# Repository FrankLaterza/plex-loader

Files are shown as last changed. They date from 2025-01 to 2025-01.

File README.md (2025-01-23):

# Plex Loader
A PCB designed to route traffic for flashing many devices with one central programmer.

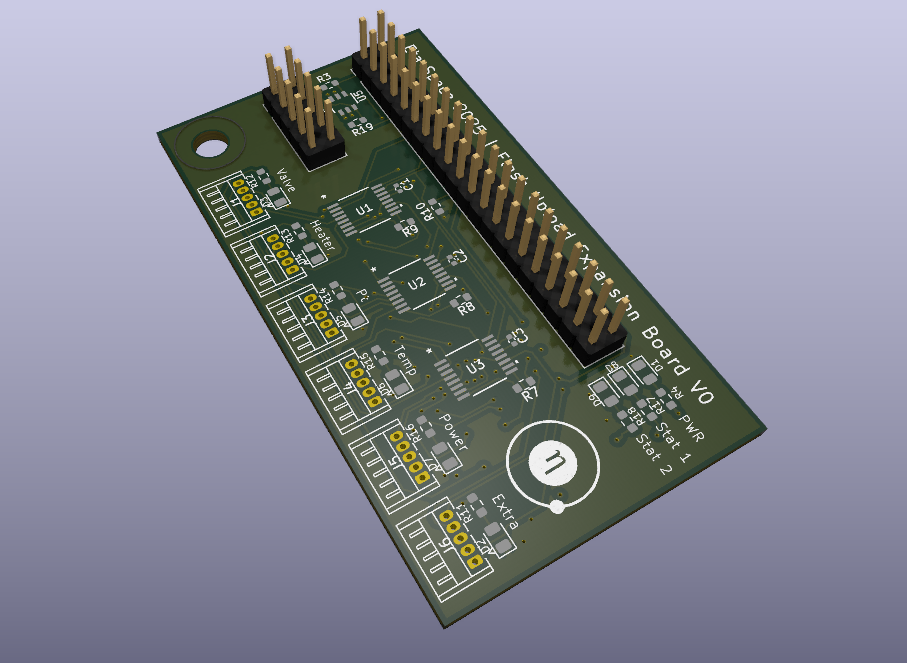
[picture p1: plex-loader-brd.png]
alttxt


BOM (per unit) 💣
| Parts | QT | Description | Link |
|---|---|---|---|
| TMUX1208 | 3 | Bidirectional Multiplexer | [link](https://digikey.com/en/products/detail/texas-instruments/TMUX1208PWR/9746210) |
dsPIC33f | 1 | An extra PIC for testing | [link](https://www.digikey.com/en/products/detail/microchip-technology/DSPIC33FJ128GP204-E-PT/1635665) |
| MOSFET PNP | 1 | Used as pain power switch | [link](https://www.digikey.com/en/products/detail/vishay-siliconix/sq3457ev-t1-ge3/7566744) |
| 0.1uf Cap | 5 | Decoupling cap used for Mux and Pic | [link](https://www.digikey.com/en/products/detail/murata-electronics/GRM155R71C104KA88J/2610892) |
| 10uf Cap | 1 | Decoupling cap on Pic | [link](https://www.digikey.com/en/products/detail/yageo/CC0603KRX5R6BB106/5195191) |
| 10k res | 5 | General pull up | [link](https://www.digikey.com/en/products/detail/yageo/RC0603JR-0710KL/726700) |
| 1k res | 9 | Pull up and led | [link](https://www.digikey.com/en/products/detail/yageo/RC0603JR-0710KL/726700https://www.digikey.com/en/products/detail/yageo/RC0402JR-071KL/726408) |
| 100 res | 3 | Used in on MCLR on pic | [link](https://www.digikey.com/en/products/detail/yageo/RC0603FR-07100RL/726888) |
| 50 res | 2 | Used in on PGC and PGD on pic | [link](https://www.digikey.com/en/products/detail/yageo/RT0603BRE0750RL/5928059) |
| DF13-5P-1.25DS | 6 | Female conn used for program out | [link](https://www.digikey.com/en/products/detail/hirose-electric-co-ltd/DF13-5P-1-25DS-25/15997289) |
| DF13-5S-1.25C | 6 | Male conn for harness | [link](https://www.digikey.com/en/products/detail/hirose-electric-co-ltd/DF13-5S-1-25C/241752) |
| H4BXG-10112-R6 | 6 | Red wire 12"| [link](https://www.digikey.com/en/products/detail/hirose-electric-co-ltd/H4BXG-10112-R6/426070) |
| H4BBG-10112-G6 | 6 | Green wire 12" | [link](https://www.digikey.com/en/products/detail/hirose-electric-co-ltd/H4BBG-10112-G6/425566) |
| H4BBG-10112-L6 | 6 | Blue wire 12" | [link](https://www.digikey.com/en/products/detail/hirose-electric-co-ltd/H4BBG-10112-L6/425574) |
| H4BBG-10112-W6 | 6 | White wire 12"| [link](https://www.digikey.com/en/products/detail/hirose-electric-co-ltd/H4BBG-10112-W6/425614) |
| H4BBG-10112-B6 | 6 | Black wire 12"| [link](https://www.digikey.com/en/products/detail/hirose-electric-co-ltd/H4BBG-10112-B6/425558) |
| LED | 6 | Green LED for prog status | [link](https://www.digikey.com/en/products/detail/ams-osram-usa-inc/LG-R971-KN-1-0-20-R18/1227925) |
| LED | 1 | RED LED for POWER | [link](https://www.digikey.com/en/products/detail/w%C3%BCrth-elektronik/150080AS75000/11479384https://www.digikey.com/en/products/detail/w%C3%BCrth-elektronik/150080RS75000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) |
| LED | 2 | Yellow LED for status | [link](https://www.digikey.com/en/products/detail/w%C3%BCrth-elektronik/150080YS75000/4489927) |
| 40-Pin Header | 1 | 20x2 pin GPIO connector designed to fit on top of the pi carrier | [link](https://www.amazon.com/2-54mm-Pitch-Female-Double-Header/dp/B083RYV9J1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) |
| 10-Pin Header| 1 | 2x5 used for cm4 configs | [link](https://www.amazon.com/ZYAMY-2-54mm-Straight-Stackable-Connector/dp/B0778M5P1W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) |

Label Guide

| Components | Value/Part Number |
|---|---|
| C1, C2, C3, C4, C5 | 0.1 µF |
| C6 | 10 µF |
| D1, D2, D3, D4, D5, D6, D7, D8, D9 | LED |
| J1, J2, J3, J4, J5, J6 | DF13-5P-1.25DS |
| J9 | 40-Pin Header |
| J10 | 10-Pin Header |
| R1, R3, R5, R6, R10 | 10 kΩ |
| R4, R11, R12, R13, R14, R15, R16, R17, R18 | 1 kΩ |
| R2, R9 R19 | 100 Ω |
| R7, R8 | 50 Ω |
| U1, U2, U3 | TMUX1208PWR |
| U4 | dsPIC33f |
| U5 | MOSFET PNP |

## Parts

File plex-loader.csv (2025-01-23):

Reference | Value | Datasheet | Footprint | Qty | DNP
C1,C2,C3,C4,C5 | 0.1uF | ~ | Capacitor_SMD:C_0402_1005Metric | 5
C6 | 10uf | ~ | Capacitor_SMD:C_0603_1608Metric | 1
D1,D2,D3,D4,D5,D6,D7,D8,D9 | LED | ~ | LED_SMD:LED_0805_2012Metric | 9
J1,J2,J3,J4,J5,J6 | Conn_01x05_Pin | ~ | Connector_Hirose:Hirose_DF13-05P-1.25DS_1x05_P1.25mm_Horizontal | 6
J9 | Conn_02x20_Odd_Even | ~ | Connector_PinHeader_2.54mm:PinHeader_2x20_P2.54mm_Vertical | 1
J10 | Conn_02x05_Odd_Even | ~ | Connector_PinHeader_2.54mm:PinHeader_2x05_P2.54mm_Vertical | 1
R1,R3,R5,R6,R10 | 10k | ~ | Resistor_SMD:R_0603_1608Metric | 5
R2,R9,R19 | 100 | ~ | Resistor_SMD:R_0603_1608Metric | 3
R4,R11,R12,R13,R14,R15,R16,R17,R18 | 1k | ~ | Resistor_SMD:R_0603_1608Metric | 9
R7,R8 | 50 | ~ | Resistor_SMD:R_0603_1608Metric | 2
U1,U2,U3 | TMUX1208PWR | TMUX1208PWR | PW_16_TEX | 3
U4 | DSPIC33FJ128GP204 | http://ww1.microchip.com/downloads/en/DeviceDoc/70292G.pdf | Package_QFP:TQFP-44_10x10mm_P0.8mm | 1
U5 | SQ3457EV-T1_BE3 | SQ3457EV-T1_BE3 | MOSFET-P:TSOP_7EV-T1_BE3_VIS | 1

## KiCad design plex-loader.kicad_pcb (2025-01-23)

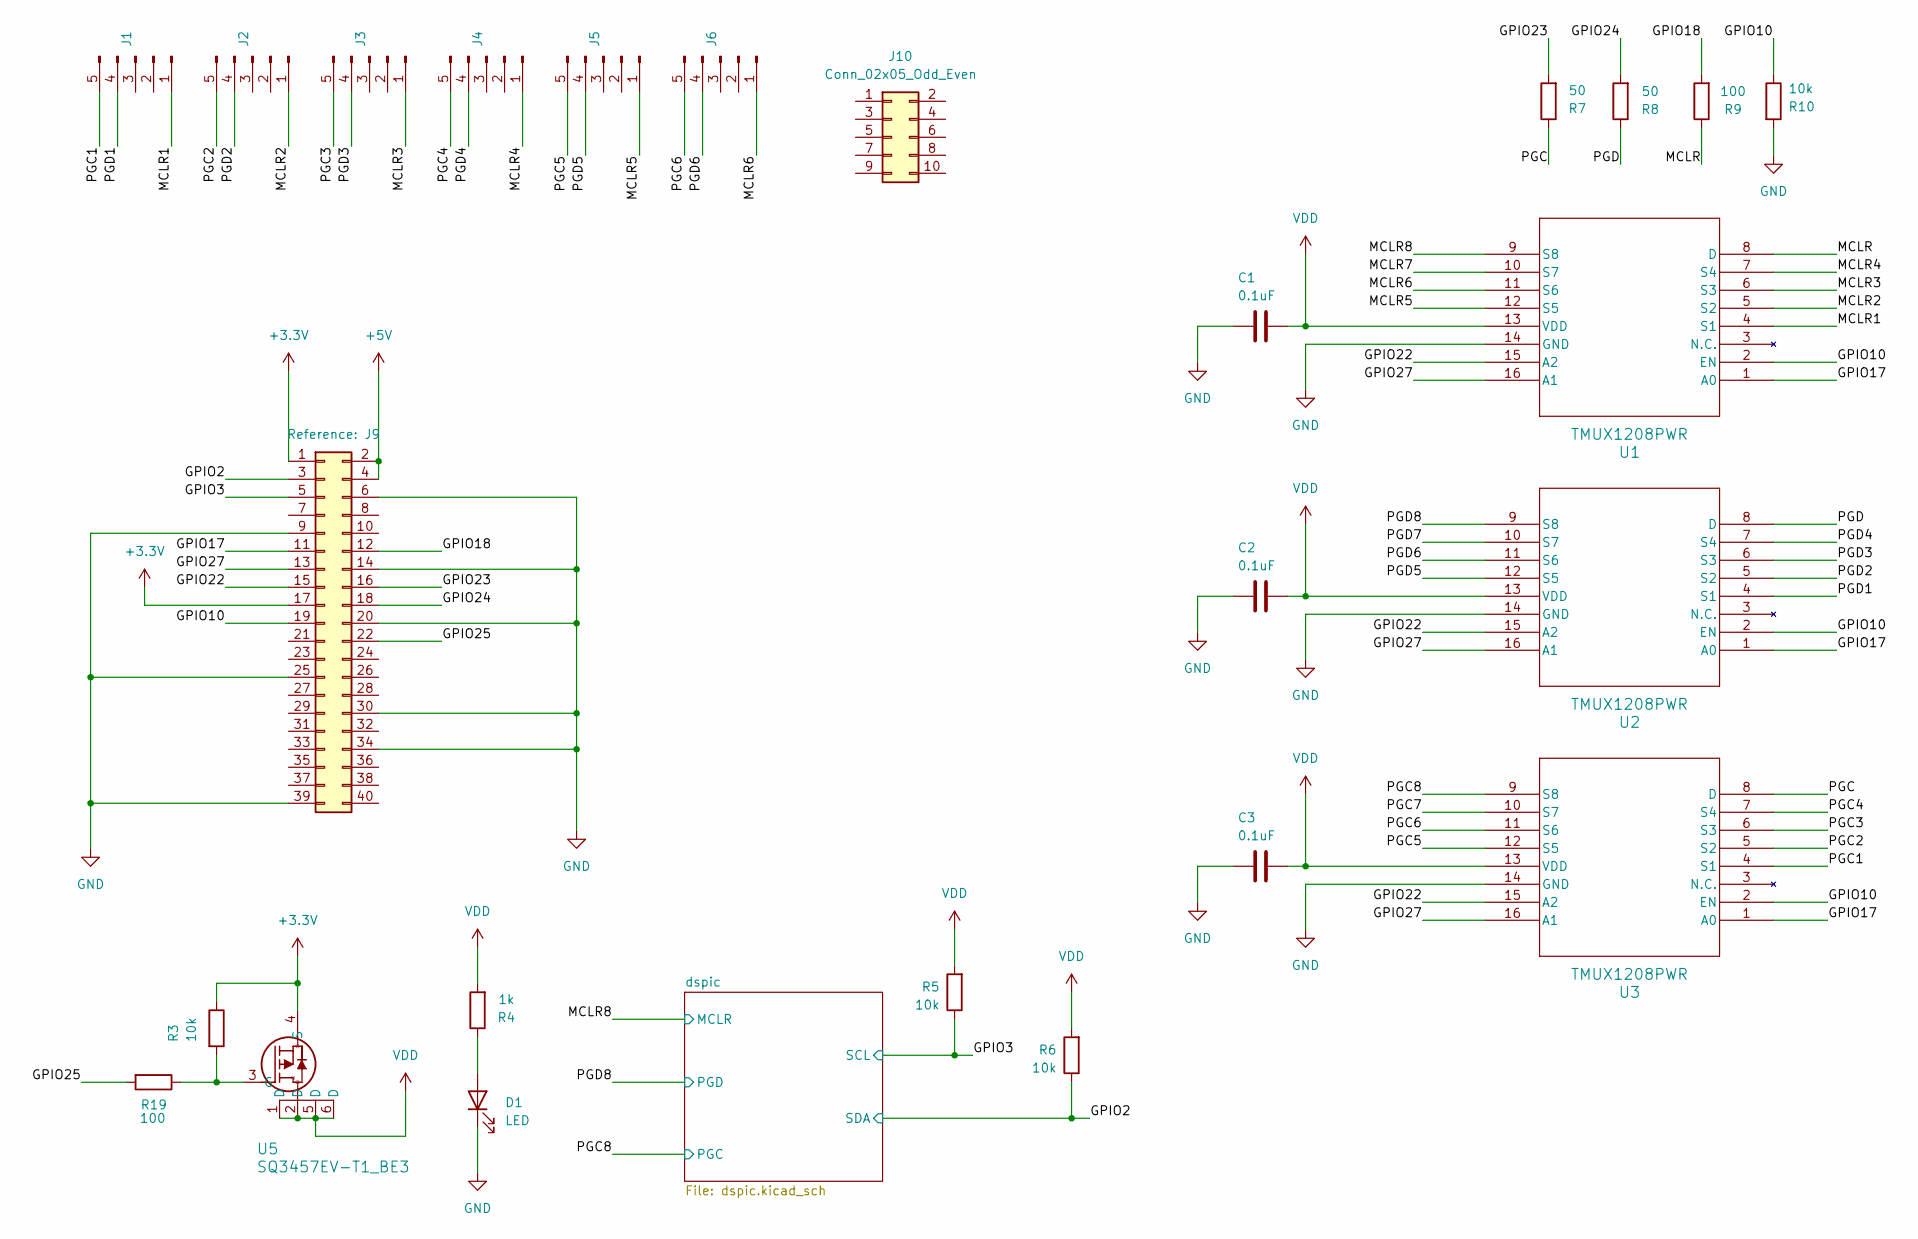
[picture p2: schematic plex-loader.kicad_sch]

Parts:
C1, C2, C3: 0.1uF; C_0402_1005Metric
D1: LED; LED_0805_2012Metric
J1, J2, J3, J4, J5, J6: Conn_01x05_Pin; Hirose_DF13-05P-1.25DS_1x05_P1.25mm_Horizontal
J9: Conn_02x20_Odd_Even; PinHeader_2x20_P2.54mm_Vertical
J10: Conn_02x05_Odd_Even; PinHeader_2x05_P2.54mm_Vertical
R3, R5, R6, R10: 10k; R_0603_1608Metric
R4: 1k; R_0603_1608Metric
R7, R8: 50; R_0603_1608Metric
R9, R19: 100; R_0603_1608Metric
U1, U2, U3: TMUX1208PWR; PW_16_TEX
U5: SQ3457EV-T1_BE3; TSOP_7EV-T1_BE3_VIS

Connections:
+3.3V: J9.1, J9.17, R3.1, U5.4 (S)
+5V: J9.2, J9.4
/GPIO2: J9.3, R6.1; also elsewhere on the board
/GPIO3: J9.5, R5.1; also elsewhere on the board
/GPIO10: J9.19, R10.1, U1.2 (EN), U2.2 (EN), U3.2 (EN)
/GPIO17: J9.11, U1.1 (A0), U2.1 (A0), U3.1 (A0)
/GPIO18: J9.12, R9.2
/GPIO22: J9.15, U1.15 (A2), U2.15 (A2), U3.15 (A2)
/GPIO23: J9.16, R7.2
/GPIO24: J9.18, R8.2
/GPIO25: J9.22, R19.2
/GPIO27: J9.13, U1.16 (A1), U2.16 (A1), U3.16 (A1)
/MCLR: R9.1, U1.8 (D)
/MCLR1: J1.1, U1.4 (S1)
/MCLR2: J2.1, U1.5 (S2)
/MCLR3: J3.1, U1.6 (S3)
/MCLR4: J4.1, U1.7 (S4)
/MCLR5: J5.1, U1.12 (S5)
/MCLR6: J6.1, U1.11 (S6)
/MCLR7: U1.10 (S7)
/MCLR8: U1.9 (S8); also elsewhere on the board
/PGC: R7.1, U3.8 (D)
/PGC1: J1.5, U3.4 (S1)
/PGC2: J2.5, U3.5 (S2)
/PGC3: J3.5, U3.6 (S3)
/PGC4: J4.5, U3.7 (S4)
/PGC5: J5.5, U3.12 (S5)
/PGC6: J6.5, U3.11 (S6)
/PGC7: U3.10 (S7)
/PGC8: U3.9 (S8); also elsewhere on the board
/PGD: R8.1, U2.8 (D)
/PGD1: J1.4, U2.4 (S1)
/PGD2: J2.4, U2.5 (S2)
/PGD3: J3.4, U2.6 (S3)
/PGD4: J4.4, U2.7 (S4)
/PGD5: J5.4, U2.12 (S5)
/PGD6: J6.4, U2.11 (S6)
/PGD7: U2.10 (S7)
/PGD8: U2.9 (S8); also elsewhere on the board
GND: C1.1, C2.1, C3.1, D1.1 (K), J9.6, J9.9, J9.14, J9.20, J9.25, J9.30, J9.34, J9.39, R10.2, U1.14 (GND), U2.14 (GND), U3.14 (GND); also elsewhere on the board
unnamed: D1.2 (A), R4.1
unnamed: R3.2, R19.1, U5.3 (G)
VDD: C1.2, C2.2, C3.2, R4.2, R5.2, R6.2, U1.13 (VDD), U2.13 (VDD), U3.13 (VDD), U5.1 (D), U5.2 (D), U5.5 (D), U5.6 (D); also elsewhere on the board

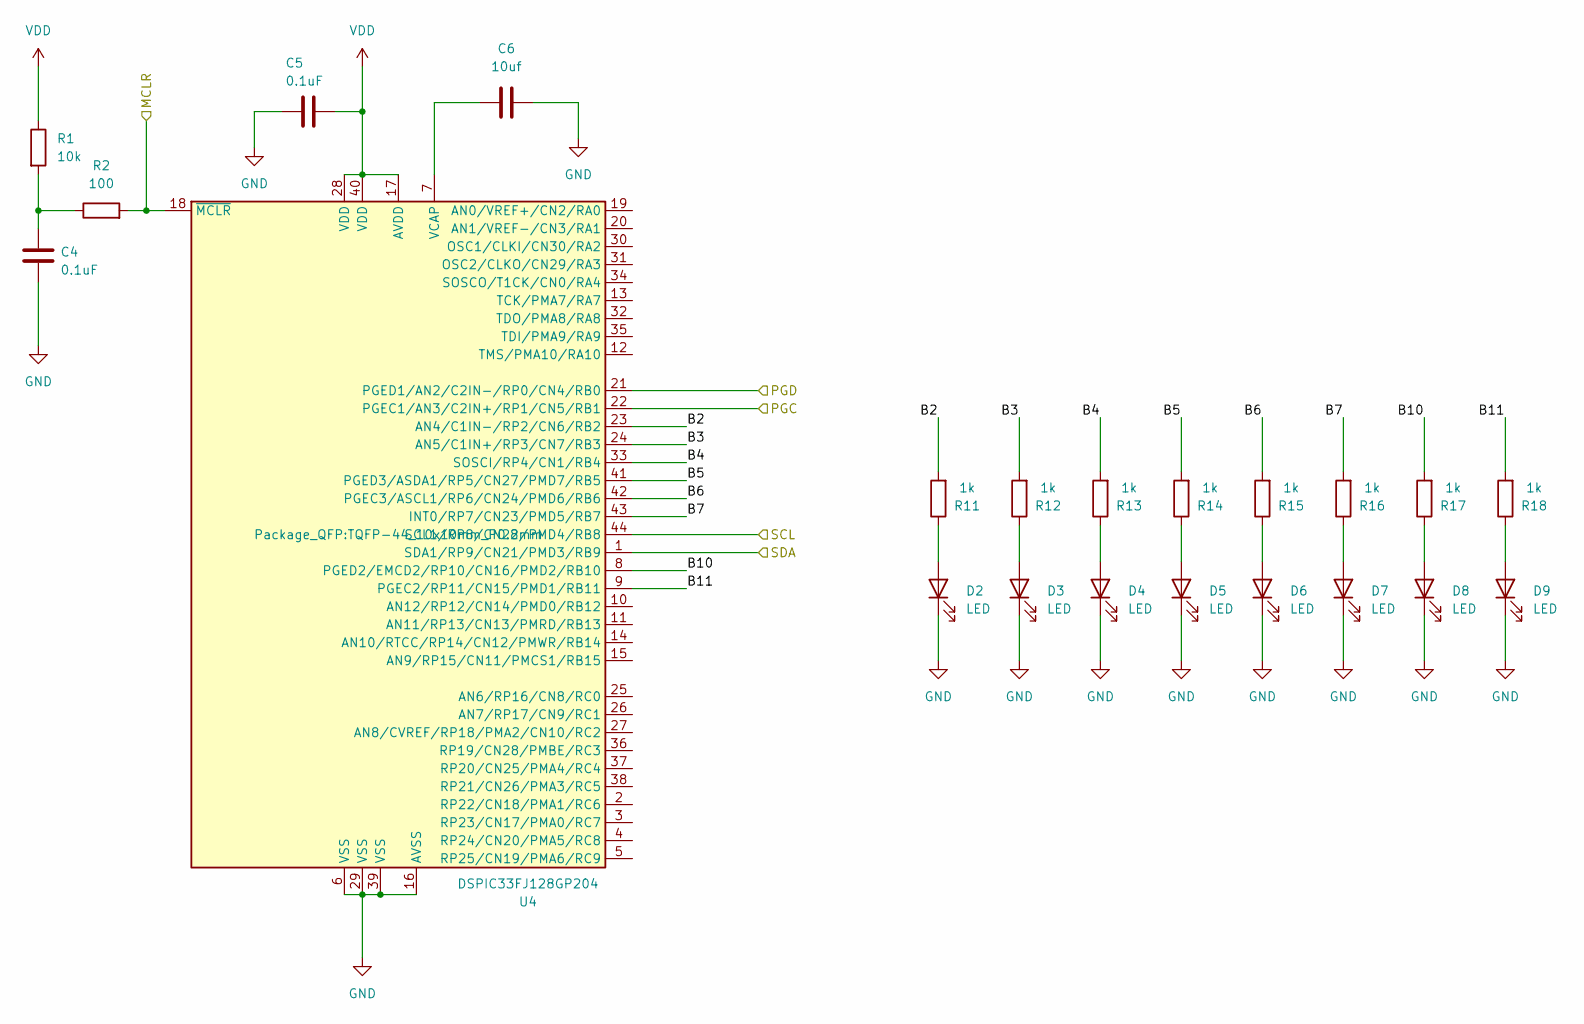
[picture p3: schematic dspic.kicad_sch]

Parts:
C4, C5: 0.1uF; C_0402_1005Metric
C6: 10uf; C_0603_1608Metric
D2, D3, D4, D5, D6, D7, D8, D9: LED; LED_0805_2012Metric
R1: 10k; R_0603_1608Metric
R2: 100; R_0603_1608Metric
R11, R12, R13, R14, R15, R16, R17, R18: 1k; R_0603_1608Metric
U4: DSPIC33FJ128GP204; TQFP-44_10x10mm_P0.8mm

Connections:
/GPIO2: U4.1 (SDA1/RP9/CN21/PMD3/RB9); also elsewhere on the board
/GPIO3: U4.44 (SCL1/RP8/CN22/PMD4/RB8); also elsewhere on the board
/MCLR8: R2.2, U4.18 (~MCLR); also elsewhere on the board
/PGC8: U4.22 (PGEC1/AN3/C2IN+/RP1/CN5/RB1); also elsewhere on the board
/PGD8: U4.21 (PGED1/AN2/C2IN-/RP0/CN4/RB0); also elsewhere on the board
/dspic/B2: R11.2, U4.23 (AN4/C1IN-/RP2/CN6/RB2)
/dspic/B3: R12.2, U4.24 (AN5/C1IN+/RP3/CN7/RB3)
/dspic/B4: R13.2, U4.33 (SOSCI/RP4/CN1/RB4)
/dspic/B5: R14.2, U4.41 (PGED3/ASDA1/RP5/CN27/PMD7/RB5)
/dspic/B6: R15.2, U4.42 (PGEC3/ASCL1/RP6/CN24/PMD6/RB6)
/dspic/B7: R16.2, U4.43 (INT0/RP7/CN23/PMD5/RB7)
/dspic/B10: R17.2, U4.8 (PGED2/EMCD2/RP10/CN16/PMD2/RB10)
/dspic/B11: R18.2, U4.9 (PGEC2/RP11/CN15/PMD1/RB11)
GND: C4.1, C5.1, C6.2, D2.1 (K), D3.1 (K), D4.1 (K), D5.1 (K), D6.1 (K), D7.1 (K), D8.1 (K), D9.1 (K), U4.6 (VSS), U4.16 (AVSS), U4.29 (VSS), U4.39 (VSS); also elsewhere on the board
unnamed: C4.2, R1.2, R2.1
unnamed: D2.2 (A), R11.1
unnamed: D3.2 (A), R12.1
unnamed: D4.2 (A), R13.1
unnamed: D5.2 (A), R14.1
unnamed: D6.2 (A), R15.1
unnamed: D7.2 (A), R16.1
unnamed: D8.2 (A), R17.1
unnamed: D9.2 (A), R18.1
unnamed: C6.1, U4.7 (VCAP)
VDD: C5.2, R1.1, U4.17 (AVDD), U4.28 (VDD), U4.40 (VDD); also elsewhere on the board

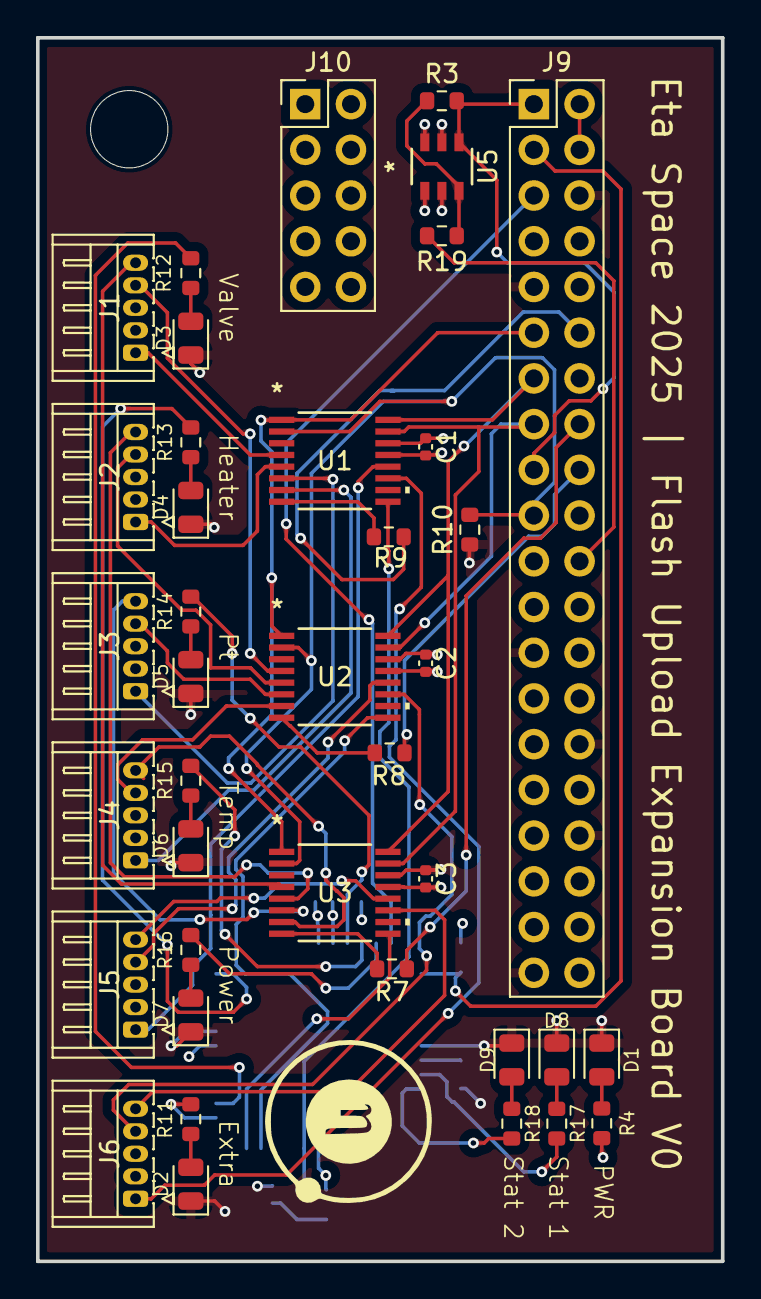
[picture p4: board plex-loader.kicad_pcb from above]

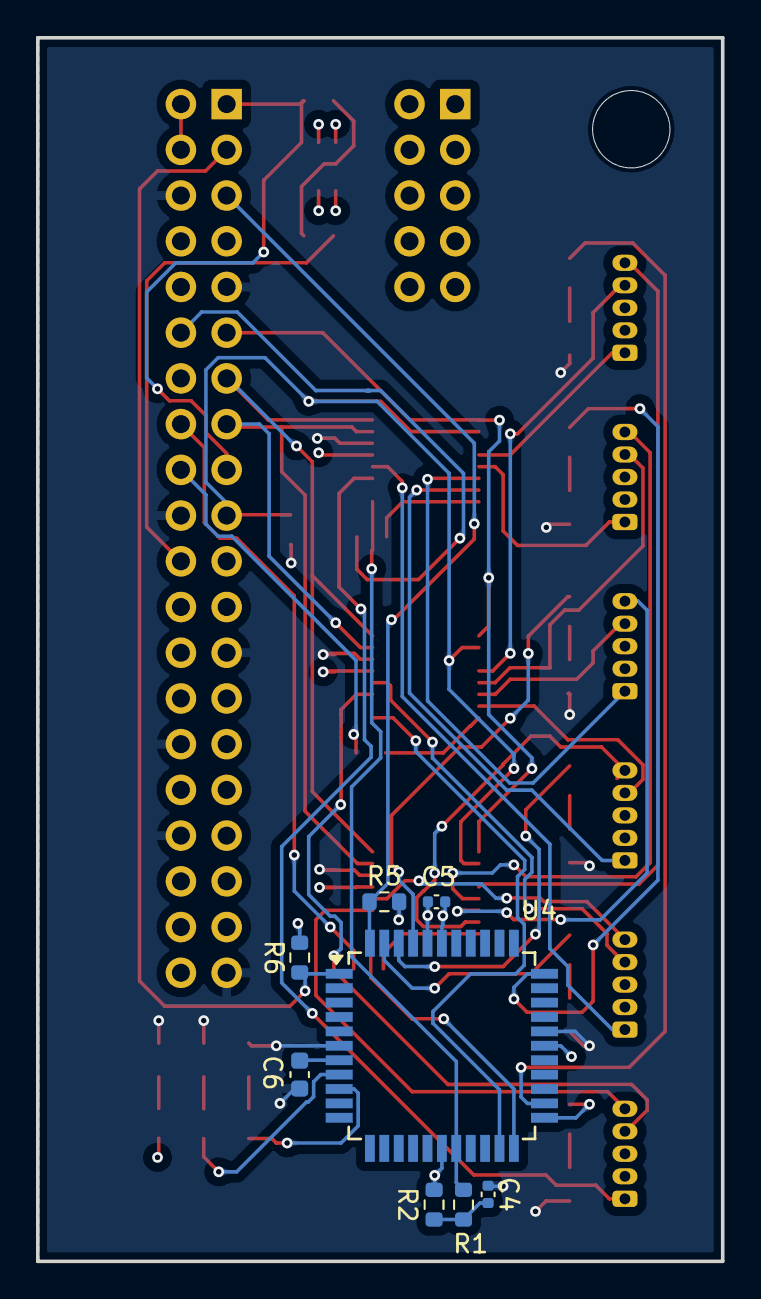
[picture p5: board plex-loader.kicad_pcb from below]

Board: 4 copper layers, 38.1 x 68.0 mm, 47 parts (8 on the bottom side), 58 nets.

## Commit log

2025-01-12 switched footprint
    [plex-loader.kicad_pcb, plex-loader.kicad_sch]
2025-01-15 update layers
    [dspic.kicad_sch, plex-loader.kicad_pcb, plex-loader.kicad_sch]
2025-01-18 curtis changes
    [dspic.kicad_sch, plex-loader.kicad_pcb]
2025-01-18 route draft
    [plex-loader-B_Cu.gbr, plex-loader-B_Mask.gbr, plex-loader-B_Paste.gbr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]
2025-01-18 trace touchup
    [plex-loader.kicad_pcb]
2025-01-18 fix res val
    [plex-loader.csv, plex-loader.kicad_pcb]
2025-01-18 removed pad via
    [dspic.kicad_sch, plex-loader.kicad_pcb]
2025-01-23 final 0v
    [plex-loader-B_Cu.gbr, plex-loader-B_Mask.gbr, plex-loader-B_Paste.gbr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]
2025-01-23 updated grbr
    [plex-loader-B_Cu.gbr, plex-loader-B_Mask.gbr, plex-loader-B_Paste.gbr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]
2025-01-23 added readme
    [plex-loader.csv]
2025-01-23 update bom
2025-01-23 fixed bom
